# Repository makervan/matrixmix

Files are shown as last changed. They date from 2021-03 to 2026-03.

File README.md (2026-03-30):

# MatrixMix

Matrix mixer. Currently only 4 inputs, 4 outputs, passive. Option for passthrough sync. There's an extension port to chain mulitple mixers together, for more inputs, or add a separate amplifer for the outputs.

OSHW Certification Mark DE000158

## License
Created by Severin Schols, and shared under CC-BY-SA-4.0. See LICENSE for more information.

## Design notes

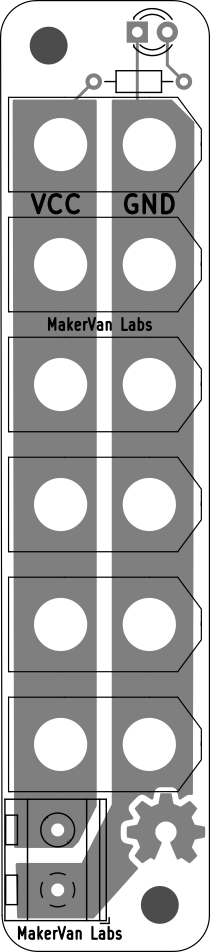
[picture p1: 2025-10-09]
passive-4x4/docs/powerhub-xt60-brd.png

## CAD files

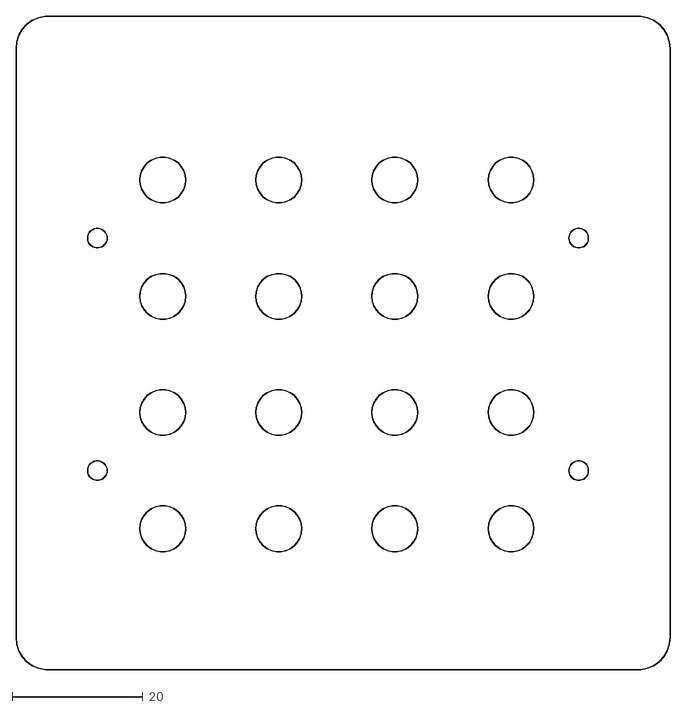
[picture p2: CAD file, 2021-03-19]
passive-4x4/case/panel.dxf
100.0 x 99.9

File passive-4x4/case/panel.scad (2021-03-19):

module round_square(w,h,r) {
    i_w=w/2-r;
    i_h=h/2-r;
    hull() {
        translate([-i_w,-i_h]) circle(r=r);
        translate([i_w,-i_h]) circle(r=r);
        translate([-i_w,i_h]) circle(r=r);
        translate([i_w,i_h]) circle(r=r);
    }
}

$fn=30;
r_pot = 3.5;
r_screw = 1.5;

pot_x = [
    22.44,
    22.44 + 17.74,
    22.44 + 17.74 * 2,
    22.44 + 17.74 * 2 + 17.78,
];
pot_y = [
    21.6,
    21.6 + 17.78,
    21.6 + 17.78 + 17.765,
    21.6 + 17.78 + 17.765 + 17.78,
];

difference() {
    translate([50,50]) round_square(100,100,5);
    
    // Screws
    translate([12.45    ,30.48      ]) circle(r_screw);
    translate([12.45    ,30.48+35.56]) circle(r_screw);
    translate([100-13.97,30.48      ]) circle(r_screw);
    translate([100-13.97,30.48+35.56]) circle(r_screw);
    // Pots
    for (x=pot_x) {
        for (y=pot_y) {
            translate([x,y]) circle(r_pot);
        }
    }
}

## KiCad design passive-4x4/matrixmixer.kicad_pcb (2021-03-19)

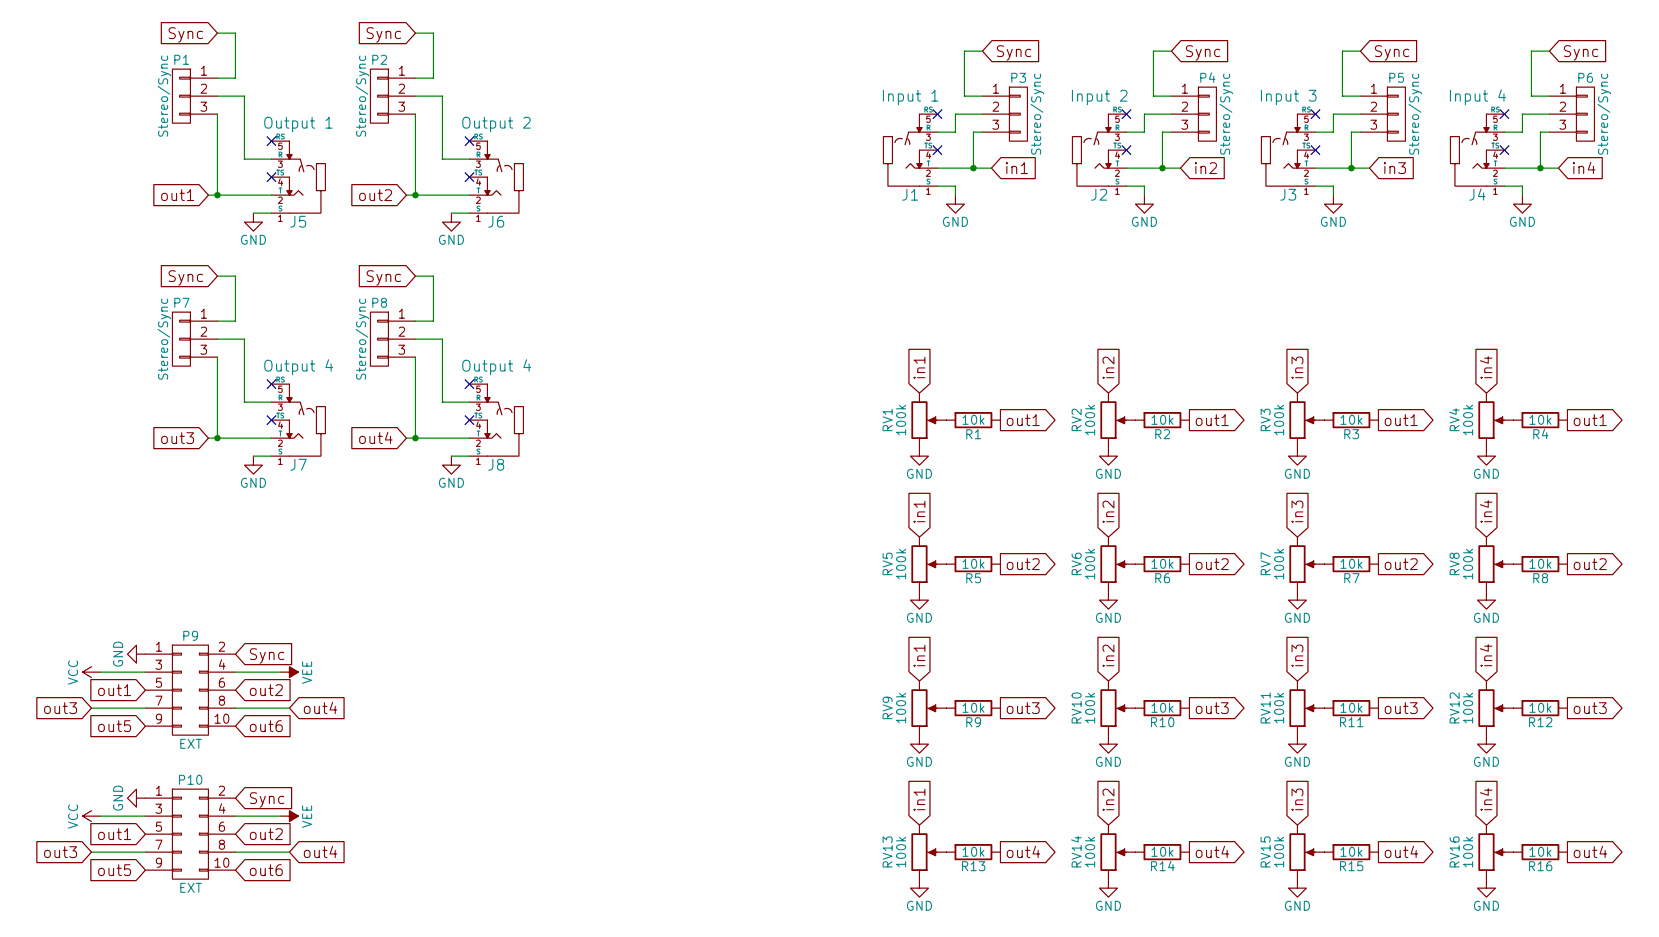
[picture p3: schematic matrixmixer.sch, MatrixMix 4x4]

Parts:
J1: Input 1; AudioJack3.5mm
J2: Input 2; AudioJack3.5mm
J3: Input 3; AudioJack3.5mm
J4: Input 4; AudioJack3.5mm
J5: Output 1; AudioJack3.5mm
J6: Output 2; AudioJack3.5mm
J7, J8: Output 4; AudioJack3.5mm
P1, P2, P3, P4, P5, P6, P7, P8: Stereo/Sync; Pin_Header_Straight_1x03
P9, P10: EXT; Pin_Header_Angled_2x05
R1, R2, R3, R4, R5, R6, R7, R8, R9, R10, R11, R12, R13, R14, R15, R16: 10k; Resistor_Horizontal_RM10mm
RV1, RV2, RV3, RV4, RV5, RV6, RV7, RV8, RV9, RV10, RV11, RV12, RV13, RV14, RV15, RV16: 100k; Potentiometer_Alpha-RV09

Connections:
GND: J1.1 (S), J2.1 (S), J3.1 (S), J4.1 (S), J5.1 (S), J6.1 (S), J7.1 (S), J8.1 (S), P9.1, P10.1, RV1.1, RV2.1, RV3.1, RV4.1, RV5.1, RV6.1, RV7.1, RV8.1, RV9.1, RV10.1, RV11.1, RV12.1, RV13.1, RV14.1, RV15.1, RV16.1
unnamed: J1.3 (R), P3.2
unnamed: J2.3 (R), P4.2
unnamed: J3.3 (R), P5.2
unnamed: J4.3 (R), P6.2
unnamed: J5.3 (R), P1.2
unnamed: J6.3 (R), P2.2
unnamed: J7.3 (R), P7.2
unnamed: J8.3 (R), P8.2
unnamed: R1.2, RV1.2
unnamed: R2.2, RV2.2
unnamed: R3.2, RV3.2
unnamed: R4.2, RV4.2
unnamed: R5.2, RV5.2
unnamed: R6.2, RV6.2
unnamed: R7.2, RV7.2
unnamed: R8.2, RV8.2
unnamed: R9.2, RV9.2
unnamed: R10.2, RV10.2
unnamed: R11.2, RV11.2
unnamed: R12.2, RV12.2
unnamed: R13.2, RV13.2
unnamed: R14.2, RV14.2
unnamed: R15.2, RV15.2
unnamed: R16.2, RV16.2
Sync: P1.1, P2.1, P3.1, P4.1, P5.1, P6.1, P7.1, P8.1, P9.2, P10.2
VCC: P9.3, P10.3
VEE: P9.4, P10.4
in1: J1.2 (T), P3.3, RV1.3, RV5.3, RV9.3, RV13.3
in2: J2.2 (T), P4.3, RV2.3, RV6.3, RV10.3, RV14.3
in3: J3.2 (T), P5.3, RV3.3, RV7.3, RV11.3, RV15.3
in4: J4.2 (T), P6.3, RV4.3, RV8.3, RV12.3, RV16.3
out1: J5.2 (T), P1.3, P9.5, P10.5, R1.1, R2.1, R3.1, R4.1
out2: J6.2 (T), P2.3, P9.6, P10.6, R5.1, R6.1, R7.1, R8.1
out3: J7.2 (T), P7.3, P9.7, P10.7, R9.1, R10.1, R11.1, R12.1
out4: J8.2 (T), P8.3, P9.8, P10.8, R13.1, R14.1, R15.1, R16.1
out5: P9.9, P10.9
out6: P9.10, P10.10

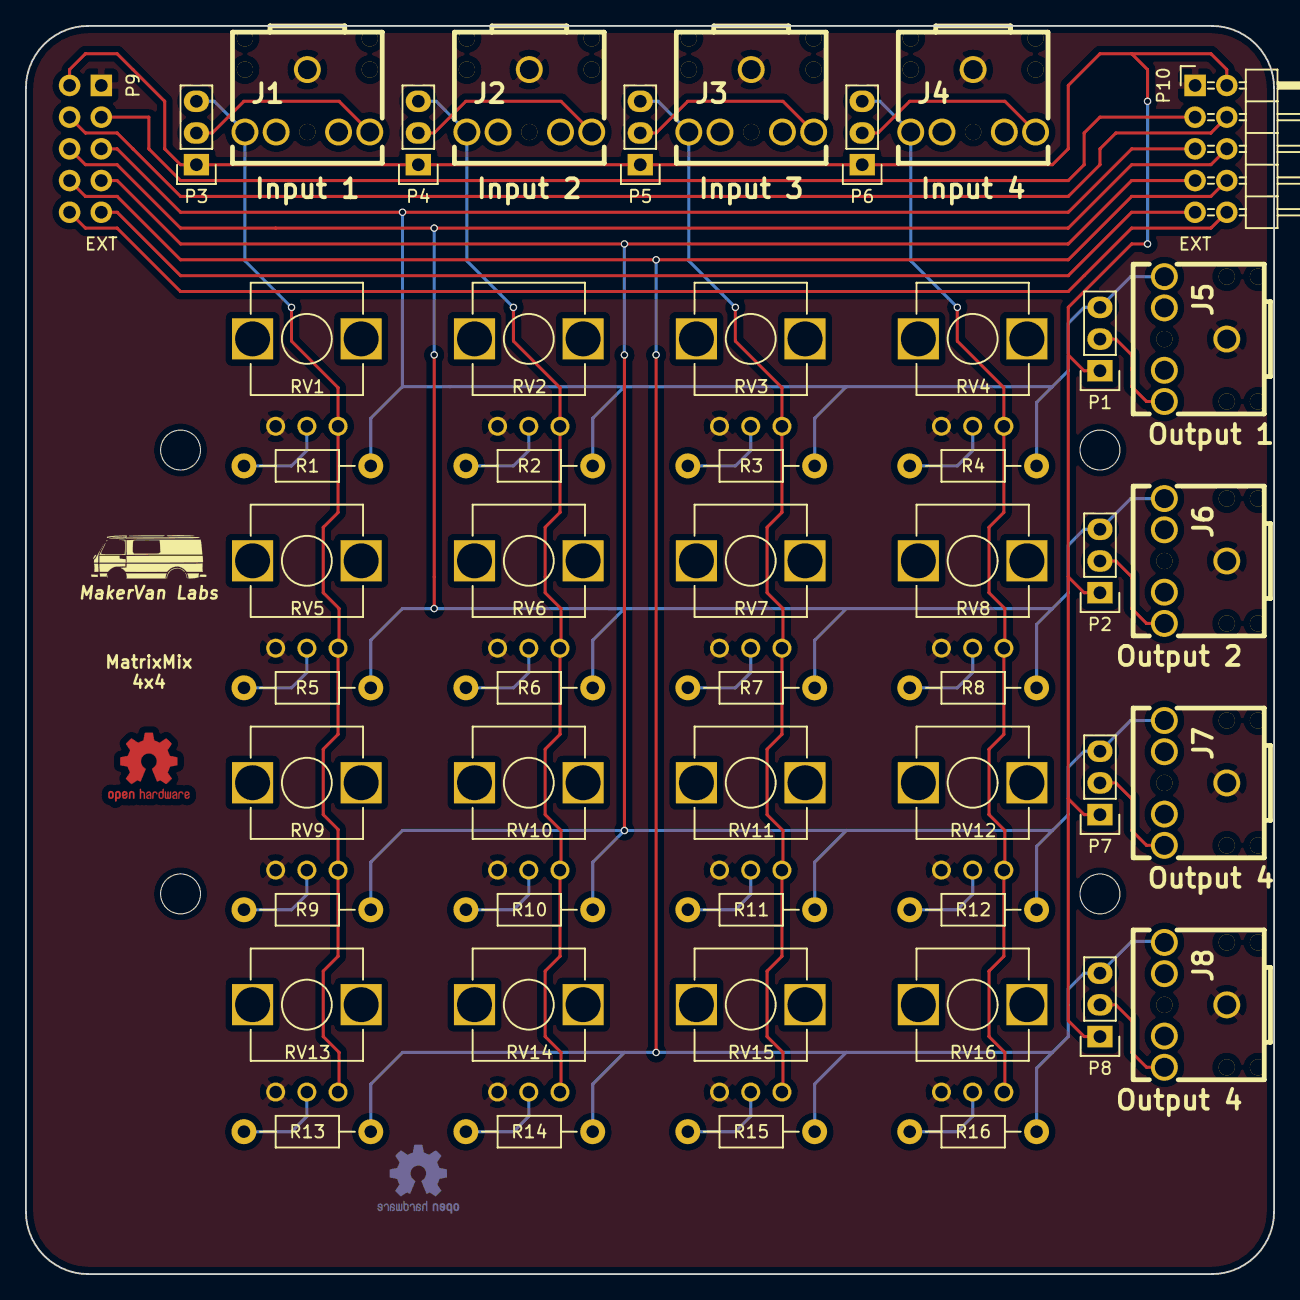
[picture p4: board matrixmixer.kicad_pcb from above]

Board: 2 copper layers, 100.0 x 100.0 mm, 50 parts (1 on the bottom side), 38 nets.

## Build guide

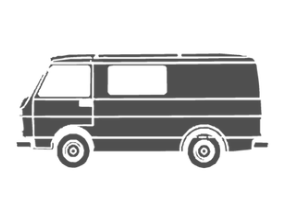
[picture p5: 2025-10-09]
passive-4x4/docs/makervan.png

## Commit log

2021-03-19 Passive 4x4 v0.2
    [matrixmixer.kicad_pcb, matrixmixer.sch]
2021-03-19 Lasercut front panel
    [panel.dxf, panel.scad]

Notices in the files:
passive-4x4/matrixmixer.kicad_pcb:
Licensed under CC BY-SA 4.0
